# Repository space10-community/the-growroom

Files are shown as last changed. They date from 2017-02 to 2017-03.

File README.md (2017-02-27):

# The Growroom

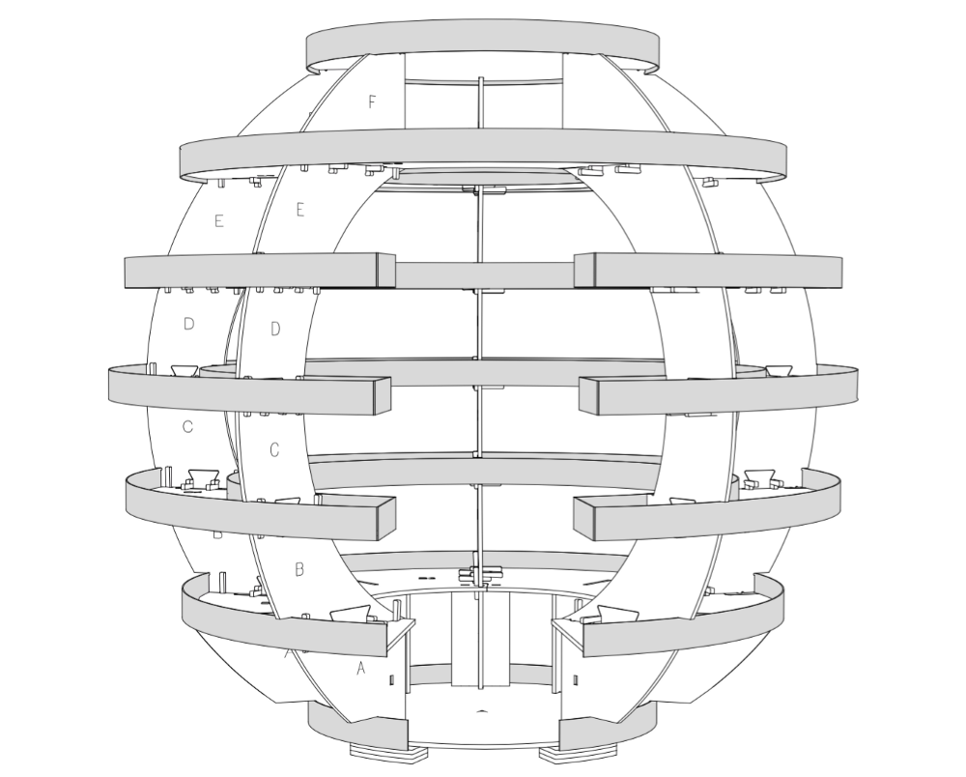
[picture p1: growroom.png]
The Growroom


SPACE10 envision a future, where we grow our own food much more locally. To spark conversations about how we can bring nature back into our cities, grow our own food and tackle the rapidly increasing demand for significantly more food in the future, we teamed up with architects Sine Lindholm and Mads-Ulrik Husum to create [The Growroom](https://medium.com/space10-the-farm/space10-open-sources-the-growroom-aa7ca6621715#.jkt6zxkk9). Standing tall as a spherical garden, it empowers people to grow their own food much more locally in a beautiful and sustainable way.

From Taipei to Helsinki and from Rio de Janeiro to San Francisco, the original version of The Growroom sparked interest and people requested to either buy or exhibit The Growroom. But it doesn’t make sense to promote local food production and then start shipping it across oceans and continents. That is why we now release The Growroom as open source design and encourage people to build their own locally as a way to bring new opportunities to life.

# Download

To download the drawings and manual, press the green "Clone or download" button in the top right, or press the shortcut below.

[Download The Growroom](https://github.com/space10-community/the-growroom/archive/master.zip)

# Terms of use



The Growroom is licensed under [Creative Commons Attribution 4.0 International License](https://creativecommons.org/licenses/by/4.0/), which means that the design can be shared, copied and build upon without asking permission. The only condition is that you credit the original work to SPACE10 and architects Mads-Ulrik Husum and Sine Lindholm, throw in a link and indicate if any changes have been made.
Good luck!

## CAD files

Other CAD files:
ASSEMBLY_OPENSOURCE_GROWROOM.dwg
PARTS_OPENSOURCE_GROWROOM_DWG/9.dwg
PARTS_OPENSOURCE_GROWROOM_DWG/10.dwg
PARTS_OPENSOURCE_GROWROOM_DWG/5.dwg
PARTS_OPENSOURCE_GROWROOM_DWG/4.dwg
PARTS_OPENSOURCE_GROWROOM_DWG/7.dwg
PARTS_OPENSOURCE_GROWROOM_DWG/2.dwg
PARTS_OPENSOURCE_GROWROOM_DWG/6.dwg
PARTS_OPENSOURCE_GROWROOM_DWG/12.dwg
PARTS_OPENSOURCE_GROWROOM_DWG/11.dwg
PARTS_OPENSOURCE_GROWROOM_DWG/8.dwg
PARTS_OPENSOURCE_GROWROOM_DWG/1.dwg
PARTS_OPENSOURCE_GROWROOM_DWG/3.dwg

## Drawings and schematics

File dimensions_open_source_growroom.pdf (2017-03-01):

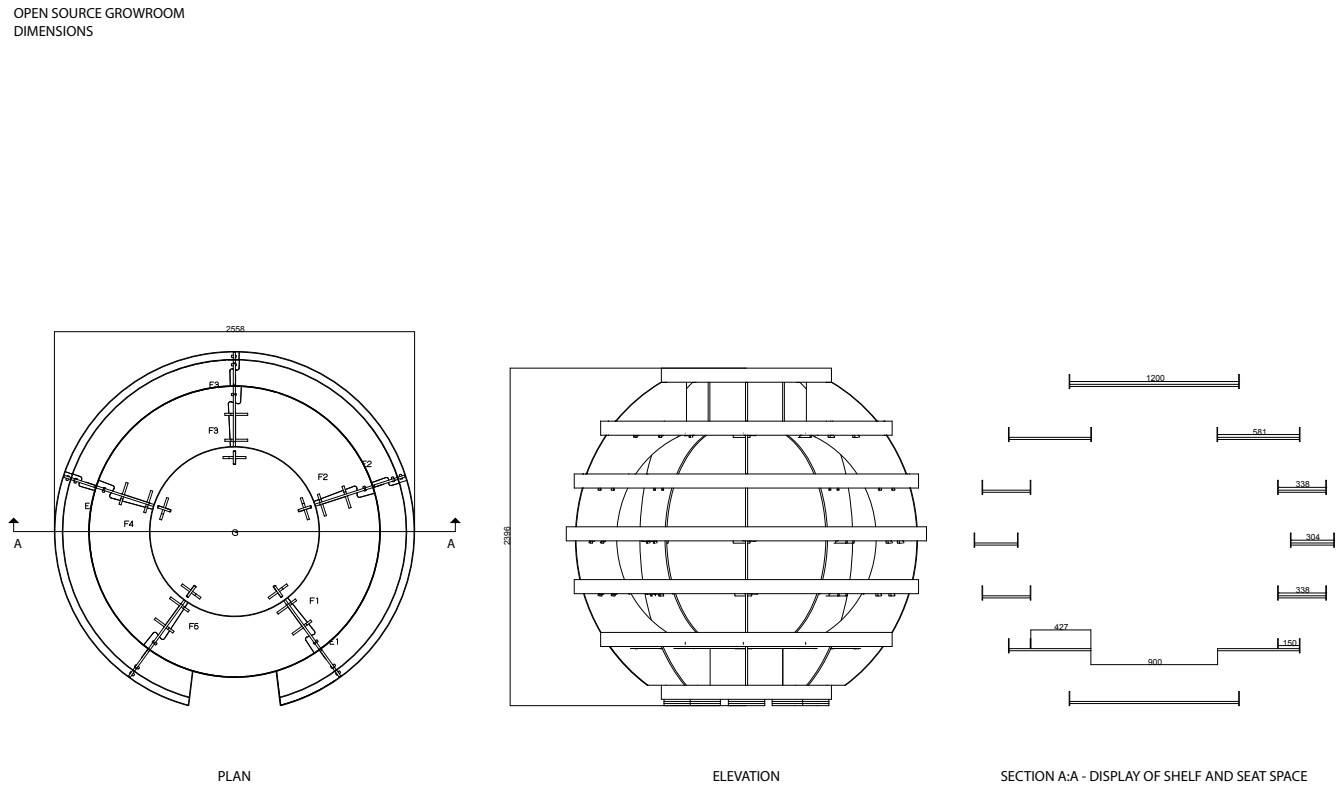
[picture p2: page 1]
PLAN; ELEVATION; SECTION A:A - DISPLAY OF SHELF AND SEAT SPACE

OPEN SOURCE GROWROOM
DIMENSIONS

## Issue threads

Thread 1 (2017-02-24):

Aquaponics version

dahousecat, 2017-02-24:
I love this desgin / concept.
But would be amazing if there was an aquaponics version of this!
Not sure where the best place to put this fish tank would be - I guess at the bottom due to weight...
Anyway, just an idea.

danielfriis, 2017-02-24:
Hi dahousecat

We’re happy to hear that you love it. The Growroom is open source and we welcome people’s input and tips on how they would adjust or optimise it. We agree that it would be amazing to see an aquaponics version of it. We’ll let you know if one pops up anywhere. If you decide to build one, please give us as nudge as we’d be curious to see it and share with everyone.

DaveYivva, 2017-02-25:
Great idea, I'd love to see an aquaponics version too. I'm following this conversation

resweet, 2017-02-26:
I would love to see this too.  The plans are amazing though - and I am looking forward to building it!

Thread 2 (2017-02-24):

How do I download the DXF file?

bigjohn2016, 2017-02-24:
Hell

Great idea and design but, I can't download the DXF file. When I click the download button, it just opens the file in the browser, it doesn't download.

Your help would be appreciated.

Regards - John

danielfriis, 2017-02-24:
Hi John,

Thanks for your interest!

On this page: https://github.com/space10-community/the-growroom
... there's a green "Clone or download" button in the top right. Use that to download a zip of the project.

Bests,
Daniel

bigjohn2016, 2017-02-24:
Hello Daniel

That’s perfect, I have it all now, thank you.

My Son showed me this and I instantly thought – half size as a herb garden for the kids, partly because my AXYZ MIllenium CNC machine only has a 1m square bed.

Thanks again for both the help and the data

Kind regards - John

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

Closed 2017-02-24.

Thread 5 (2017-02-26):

Outdoor Version

ArneBo, 2017-02-26:
It would be great to include or attach a water collection system.
I would start altering the design with a spiral of a slight slope, but for that i think the radius need to be bigger. So the water can run down from top to bottom in a spiral. The plant beds should be connected to break the water flow, no pots, but one box that can be layered with pond foil.

danielfriis, 2017-03-01:
Hi ArneBo

Thanks a lot for your input, we like your idea with self-watering. The Growroom is open source and we very much appreciate it when people tip in with how they would advance it.

anselmh, 2020-05-04:
In a first thought we might be able to install a drip watering tube into the circles…

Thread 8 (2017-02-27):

Sizing of CNC parts

hwrightcis, 2017-02-27:
Is there a more accurate document regarding the sizing of the CNC-Milled parts?
We are a school and I would love to get some students building this as a project!

danstroud85, 2017-02-28:
I agree, sizes of the parts would be useful if we need to get the plywood cut at the shop. Would also love to do this at my school. looking forward to the updates.

wrobinson04, 2017-03-01:
The CNC_OpenSource_Growroom_1  DXF File has the dimensions needed.

hwrightcis, 2017-03-02:
Thanks for the reply. Every time I try to download that file it just comes
up as text in a HTML window. Do I need to download the Github desktop in
order to download it?

Thanks

On Thu, Mar 2, 2017 at 2:08 AM, wrobinson04 <notifications@github.com>
wrote:

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

--
 Henry Wright | Head Swimming Coach | (852) 2510 7288 Ext. 815

*Phoenix Swim Team Website*
<https://sites.google.com/a/cis.edu.hk/phoenixswimteam/>

*Twitter -* @swimphoenix <https://twitter.com/swimphoenix>

<http://www.cis.edu.hk/>

asmendo, 2017-05-30:
I would like to built the growroom in the school where I work. I need the size of every piece in order to get them cut.
Thanks!!!

HusumLindholm, 2017-06-12:
Hi all,

The files have been updated, so you now can find a package consisting of each of the 12 sheets laid out in it's own file as well as a file consisting of all the sheets.
The files are 1:1 when you open them up in your CAD-program allowing you to measure each element as you see fit. The size of the sheets is 1220mm x 2440mm.
I hope this was of help to you.

Best regards
Husum&Lindholm

rsbeckerca, 2017-06-20:
Does anyone have a set of DXF files for nested CNC routers that can be added to this project? Optimized for 4x8 plywood would be cool.

Closed 2017-06-20.

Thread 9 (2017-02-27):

Number of 18mm Plywood Sheets Needed

EJN1, 2017-02-27:
The Manual specifies 13 sheets of 18mm plywood but the .dxf file only seems to show 12. What am I missing - Thanks

silicakes, 2017-03-06:
IMO, it seems like you'll be cutting several parts from each sheet - so it consolidates into less than 13.

cwiegman, 2017-04-02:
I started actually making the Growroom and before heading out to purchase the remaining 7 boards, I noticed this 12 v 13 difference too. So I made a count of parts that will be made from the dxf vs the milled diagram that we should have, and I could be wrong but I think 13 boards is the correct number. I will let you but I notice only one of the F'circle parts missing, so only half a board is needed. My plan is to actually change some of the nesting with ~80 wedges, placing some on the scrap areas of other boards, copy a 5th F into that freedup space and and only use 12 boards.

HusumLindholm, 2017-06-12:
Hi all,

It is true that you only need 12 sheets of 18mm plywood.
Regarding the missing F piece, the drawings have been updated and include all pieces - still on 12 sheets. Further more we have cleaned up the lines, so the files now consist of arcs and lines only, with much fewer control points. Furthermore we have uploadet a package that include each sheet in single files with numbers.

Best regards
Husum&Lindholm

Closed 2017-06-20.

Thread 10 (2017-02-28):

Cut list file format

LorenzoinNC, 2017-02-28:
Any chance that the cut list and plans will be issued in a format other than UNIX? A plain pdf, for example.

danielfriis, 2017-03-01:
Hi LorenzionNC. We’ve decided just to release it in the two most commonly used formats used in digital fabrication. They are not available in pdf as we wouldn’t recommend to cut the pavilion with jigsaw or other manual tools that are not hooked up to anything digital. Firstly, because it‘s hard to avoid making splits. Second, because each part needs to be cut very precisely and small inaccuracies will do that things do not fit together properly, or offset in relation to the upper layers.

Closed 2017-03-01.

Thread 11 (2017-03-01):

Plywood Thickness and Imperial vs. Metric Measurements

n8martin22, 2017-03-01:
Here is the USA we use imperial measurements and thus finding plywood that meets the 18mm thickness will either be slightly off (.688 inches or 17.475mm) or prohibitively expensive to purchase (imported birch faced at $40 USD/sheet). Will using a slightly smaller thickness material affect the product's assembly or design integrity?

dahousecat, 2017-03-01:
I didn't design this (and have not built it), however from looking at the instructions I can see that there are slots in the design where sheets need to fit (ideally) tightly in the slot. If you use different width plywood you'll need to adjust the width of these slots to match.
From having made lots of plywood structures in the past I can't imagine that taking half a millimetre of the thickness of the board used would affect the overall integrity of the structure.

silicakes, 2017-03-06:
I'm getting the same cost for birch (I'm from Israel), but I reckon it's due to the fact that it's being imported from Europe (Russia mostly) - so it does make sense.

cwiegman, 2017-04-02:
I am using the 23/32 nominal size listed at 3/4 in the store --- i think they are mislabeled. This gets be to about 0.65 inches ($34/sheet before tax)

cwiegman, 2017-05-08:
Turns out the boards had issues with being too tight of a fit. They did have stamps on them to be a 23/32 board. and measured that way, but I had to Dremel to grind wider openings in a few places and mallet a few tight fits where I wish I had just CNCed an extra 0.1" offset.

HusumLindholm, 2017-06-12:
There is an overall tolerance in all slots and connections of 1mm, in order to make assembly as easy as possible.
Depending on the quality of the plywood you choose, the thickness throughout each sheet of plywood can vary with between 1-2mm. We experienced this when we tested the Growroom with a cheap plywood consisting of few layers.

In the case of not being able to get an 18mm plywood, I suggest that you scale the drawings for that. For instance, if your sheets are 18.5mm in thickness, scale all drawings (18.5/18).

The drawings have been updated, and you can now find a package with each sheet laid out as well as a file consisting of all the sheets.

Best regards
Husum&Lindholm

mhasting2004, 2017-06-30:
Another metric/imperial issue even down here in Australia is that a 3/8" or 9.5mm compression bit is much more standard than a 8mm. This means the corner reliefs should also be large (I'd suggest 10mm diameter reather than the existing 8mm. I'm modifing the files for my machin  but its not something everyone would spot or be able to do before sending the DXF's to a local CNC shop.

Closed 2017-06-20.

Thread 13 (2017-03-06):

Suggestion: add a 3d printer/laser cut small-scale model

silicakes, 2017-03-06:
Hi, I thought it would be nice to add files for creating a small-scale model to incorporate in existing plans or design meetings.
Thanks.

HusumLindholm, 2017-06-12:
Hi Silicakes

The structure of the Growroom is based on 18mm plywood, which means that all joints and wedges fit together according to this particular thickness. This means that the Growroom can't be scaled to any size without altering the entitet structure. What you can do, however, is to scale it according to the material you wish to build it in, and experiment with the wedges. For instance, if you wish to build it in a 3mm thick material, you can scale all the drawings 1/6, as a 3mm thick material is 6 times thinner than the 18mm plywood.

I hope this can help you further.

Best regards
Husum&Lindholm

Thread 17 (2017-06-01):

Solutions on resizing scaling etc..

Machinistnc, 2017-06-01:
Hi,
I just got done cutting and assembling TheGrowroom, in the US. Same issues as some have posted.

Wrong size or file too big.
I selected each rectangle and my cad program allows me to enter 96" and 48" that scaled the panel and every shape within with a margin of error of 0.062" in 8 feet.  My program allows me to save a selection as a single drawing. I wind up with 12 dxf drawings in us dimensions

Missing part. One of the parts on the layer that requires 5 curved puzzle parts is not on a panel. When I opened the .dxf drawings in the software for tootpaths I can center vectors in material, and I cut a lot of the wedges and moved them to other panels,spread them out among the other parts, this freed up space on one sheet of plywood to add the missing part and to recut any parts that didn't turn out well.

This reduced my sheets required to12.  I used a 1/4 inch solid carbide uncut spiral bit after some sanding all the parts fit

danielfriis, 2017-06-12:
Hi @Machinistnc - Should be fixed with most recent update. Let me know if it doesn't work for you.

Closed 2017-06-12.

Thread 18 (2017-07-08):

Error on Sheet 10

mhasting2004, 2017-07-08:
Hi guys just doing a dry fit and I've noticed that there is a error on part B on DWG 10

one is missing the large slot or part A1 and the other is missing the small hole on the inboard edge for the rib supporting the second part A

mhasting2004, 2017-07-08:
found some more omissions :( ... will make a full list and post

mhasting2004, 2017-07-08:
There is an omission of holes on all B parts (Sheet 9 and 10) in addition to the above the elongated holes used to position the B verticals and the slide sideways are all but 4 missing.

irenewolters, 2017-07-13:
I just build a scale model and i am having the same problems with missing holes on the B parts.
I had to laser some extra parts for under the structure. There are only 15 on the sheets and you need 20. I also needed more wedges. All the other parts are good and the model is very easy to build.

mhasting2004, 2017-07-13:
Thanks Irene,  I had missed the number of feet. I'm a bit confuesd though as from the length of the tab on the A parts only 15 are required. the 4th would be floating free on 18mm ply.

Also when you say you had to make more wedges was that in addition to the 250 noted or was it that there are not 250 drawn in the plans. I ask as I made mine using a saw and jig (much faster and less waste) rather than using the CNC so made ~280 from memory.

mhasting2004, 2017-07-13:
I just had a quick look at the plans and I come to a required total of 270 wedges

mhasting2004, 2017-07-13:
[Modified sheet 9.zip](https://github.com/space10-community/the-growroom/files/1144894/Modified.sheet.9.zip)
[Modified sheet 10.zip](https://github.com/space10-community/the-growroom/files/1144893/Modified.sheet.10.zip)

Here are my modified sheets 9 and 10 . Note I have also changed the slots for the verticals so that it will align better and made the reliefs 10mm dia so a larger tool can be used

irenewolters, 2017-07-13:
Hi,

In the instruction manual it says you need 20 parts for uner the construction. I need the extra 5 so the growroom can be transported with a transporter carrier. I didn't count the wedges. They were very small because i build a scale model but i had to little of them. I lasert the model on 39 % and used 4 mm wood.

Greetings,

Irene

Outlook voor iOS<https://aka.ms/o0ukef> downloaden
________________________________
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

irenewolters, 2017-07-13:
Thanks

Outlook voor iOS<https://aka.ms/o0ukef> downloaden
________________________________
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

mhasting2004, 2017-07-13:
By my calculation the 50 wedges that are pushed in vertically should actually be larger than the 10 to 20mm tapers for the two wedge positions. Something like 20 to 30mm would be more suitable given the relief hole size.

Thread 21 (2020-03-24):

Open Source but propritary format?

mabushey, 2020-03-24:
I don't run Autodesk for numerous reasons. Is there any way to get this converted to a format I can import into OpenSCAD (Blows away Autodesk products) such as STL? I tried using an online converted but it just reported errors in the .dwg files.

malixsys, 2020-05-04:
Issue descriptions are probably not the proper place for subjective comments on software. :) But, as you may know, « DWG is the native format for *several* CAD packages including DraftSight, BricsCAD, IntelliCAD, Caddie and Open Design Alliance compliant applications »
Have you tried using any of those to open and convert the models?

AutoCAD itself allows to easily export to STL, maybe you can install a trial version, if available.

mabushey, 2020-05-04:
AutoCAD only runs on Windows. I have Linux and FreeBSD.

defied, 2020-05-04:
https://bit.ly/3c9fKLa

malixsys, 2020-05-04:
Did you check https://www.opendesign.com/guestfiles/oda_file_converter?

malixsys, 2020-05-04:
At worst, you can run DWG TrueView in an emulation of Windows...

https://developer.microsoft.com/en-us/microsoft-edge/tools/vms

https://knowledge.autodesk.com/support/dwg-trueview/learn-explore/caas/sfdcarticles/sfdcarticles/System-requirements-for-Autodesk-DWG-TrueView-2018.html

> Necessity is the mother of invention

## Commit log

2017-06-12 update with individual files
    [1.dwg, 10.dwg, 11.dwg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]
2019-08-27 Updated missing holes in drawings 9 and 10
    [10.dwg, 9.dwg]

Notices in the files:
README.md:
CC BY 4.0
